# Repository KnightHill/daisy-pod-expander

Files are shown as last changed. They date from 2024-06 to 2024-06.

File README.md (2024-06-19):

# POD Expander

Expander board for the [ElectroSmith POD](https://www.electro-smith.com/daisy/pod)

## OLED Expander (v 1.1)

Final version of the expander, adding OLED display, two potentiometers, and one button.
Firmware, KiCad 7 project and Gerber files included.

## List of parts
- 1 16 pin female header
- 1 7 pin female header
- 2 [10k potentiometers](https://www.amazon.com/uxcell-Carbon-Potentiometer-Variable-Resistors/dp/B07STNVSC3)
- 1 [tactile switch](https://www.amazon.com/QTEATAK-Momentary-Tactile-Button-Switch/dp/B07VSNN9S2/)
- 1 [OLED SPI display (SSD1306)](https://www.amazon.com/HiLetgo-Serial-128X64-Display-Color/dp/B01MQPQF24/)

## PCB
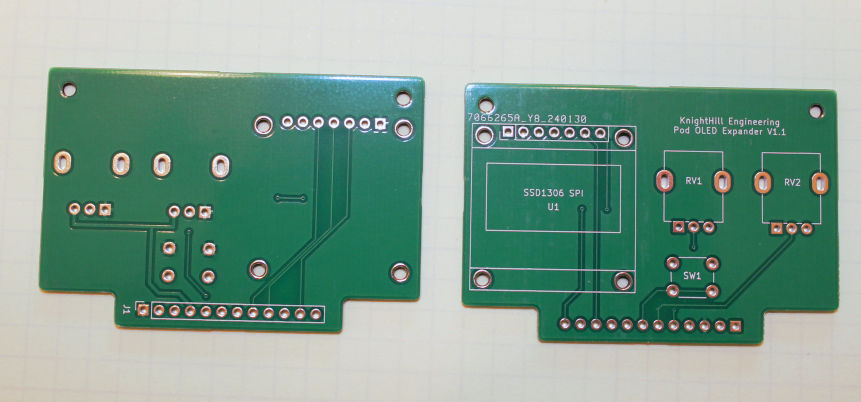
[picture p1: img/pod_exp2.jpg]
PCB

## Populated board
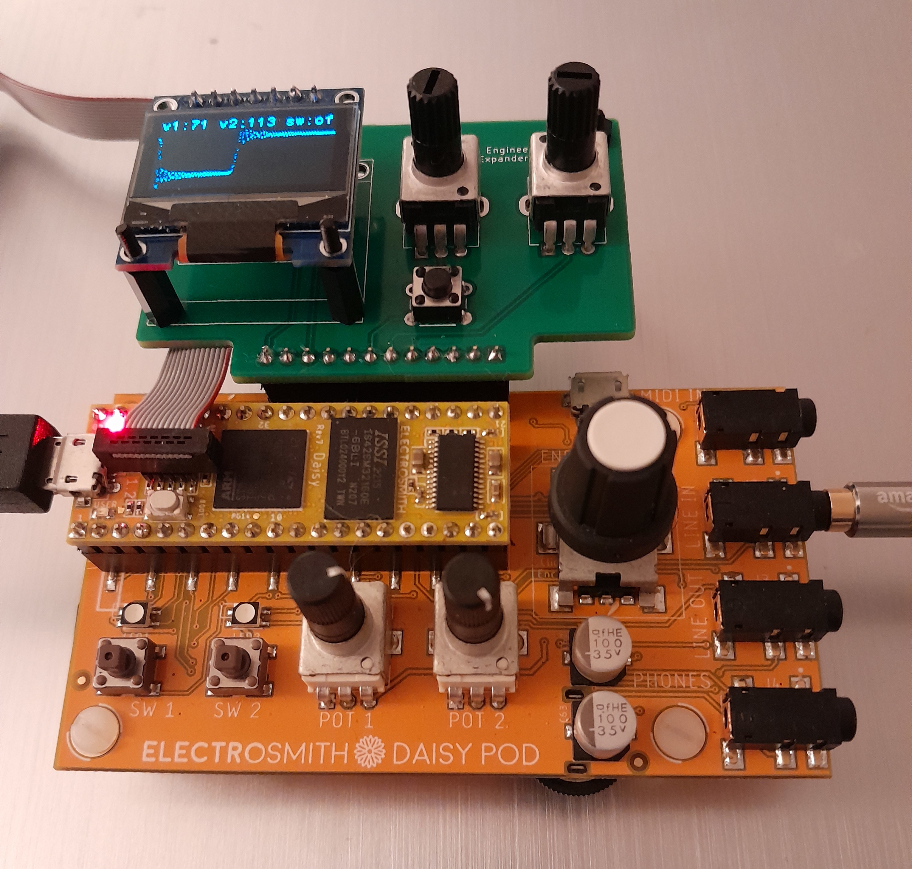
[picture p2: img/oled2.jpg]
OLED Expander v1.1


 # Disclamer

This is a hobby project. I am not affiliated with ElectroSmith in any way. I accept no responsibility for damage to you Daisy Seed, external equipment or anything else. You use this code and hardware at your own risk. All names, logos, images, and brands are property of their respective owners.

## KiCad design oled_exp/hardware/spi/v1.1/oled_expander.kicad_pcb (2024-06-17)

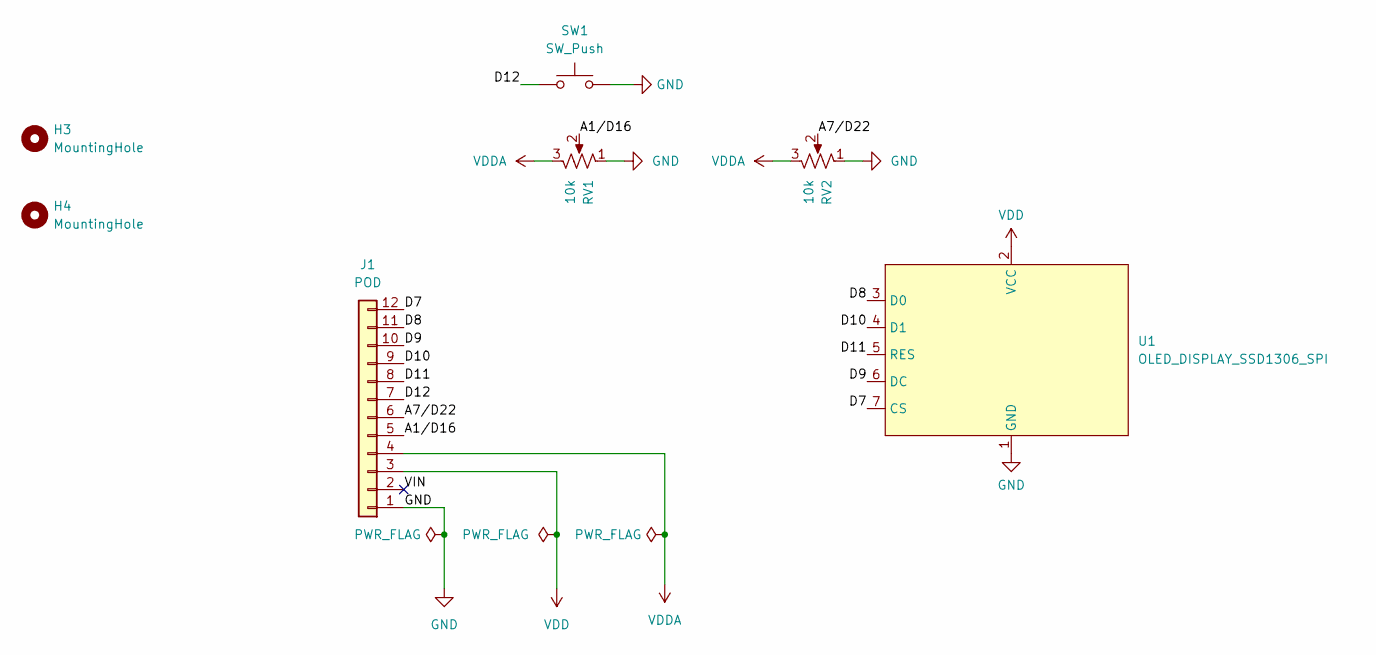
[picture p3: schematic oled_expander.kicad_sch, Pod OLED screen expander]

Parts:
H3, H4: MountingHole; MountingHole_2.2mm_M2
J1: POD; PinSocket_1x12_P2.54mm_Vertical
RV1, RV2: 10k; Potentiometer_uxcel_9mm_Single_Vertical
SW1: SW_Push; SW_PUSH_6mm
U1: OLED_DISPLAY_SSD1306_SPI; HiLetgo_OLED_SPI

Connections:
/A1/D16: J1.5, RV1.2
/A7/D22: J1.6, RV2.2
/D7: J1.12, U1.7 (CS)
/D8: J1.11, U1.3 (D0)
/D9: J1.10, U1.6 (DC)
/D10: J1.9, U1.4 (D1)
/D11: J1.8, U1.5 (RES)
/D12: J1.7, SW1.1
/VIN: J1.2
GND: J1.1, RV1.1, RV2.1, SW1.2, U1.1 (GND)
VDD: J1.3, U1.2 (VCC)
VDDA: J1.4, RV1.3, RV2.3

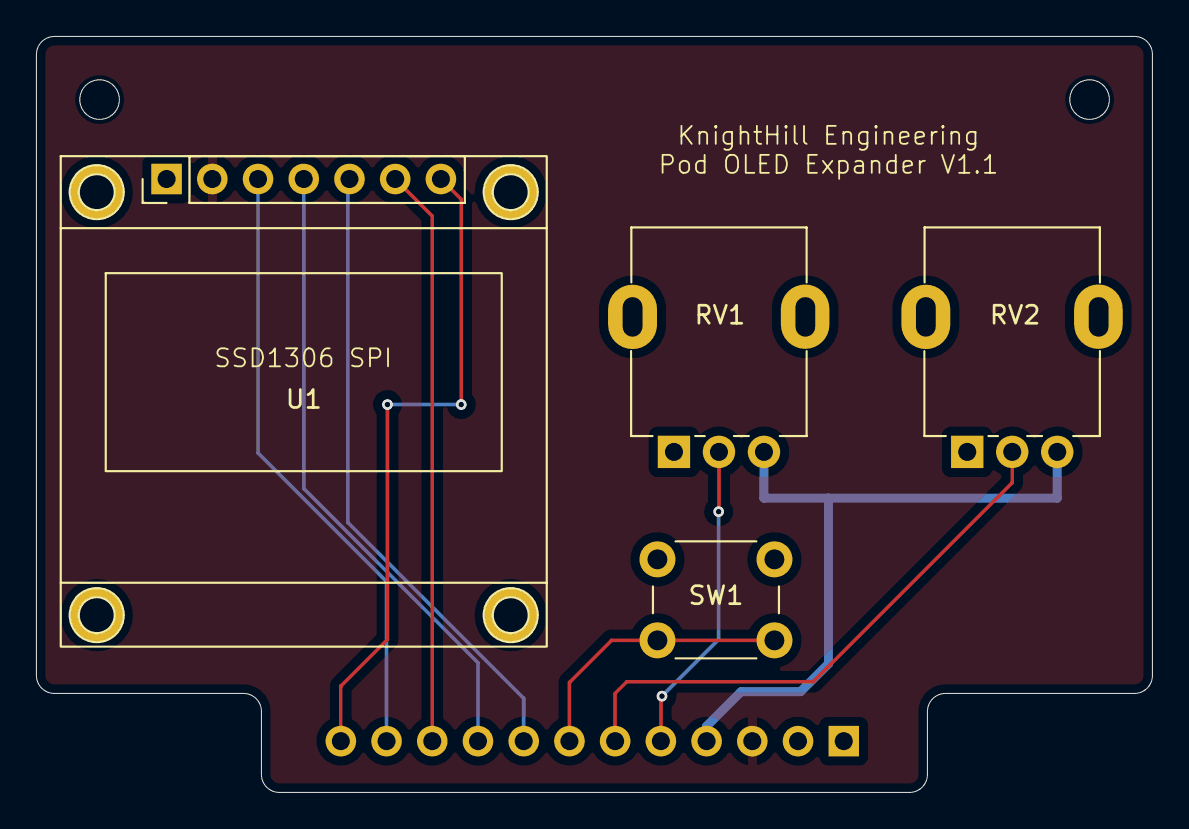
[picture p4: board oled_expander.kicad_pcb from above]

Board: 2 copper layers, 62.0 x 42.0 mm, 7 parts (1 on the bottom side), 11 nets.

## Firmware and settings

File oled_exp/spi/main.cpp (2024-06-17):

#include <stdio.h>
#include <string.h>
#include "daisy_seed.h"
#include "dev/oled_ssd130x.h"
#include "oled_exp.h"

using namespace daisy;

static OledExp hw;

static char line1[128];
static char line2[128];
static float knob1_value;
static float knob2_value;
static bool sw1;

const uint16_t ScreenWidth = 128;
static float m_scopeBuffer[ScreenWidth];
static uint16_t m_bufferIndex;

void show_info()
{
  Rectangle topRowRect(hw.display.Width(), 20);
  Rectangle secondRowRect(0, 21, hw.display.Width(), 10);
  hw.display.Fill(false);
  hw.display.WriteStringAligned(line1, Font_11x18, topRowRect, Alignment::centered, true);
  hw.display.WriteStringAligned(line2, Font_7x10, secondRowRect, Alignment::centered, true);
  hw.display.Update();
  System::Delay(1000);
}

void show_logo()
{
  sprintf(line1, "KnightHill");
  sprintf(line2, "Engineering");
  show_info();
}

void show_product()
{
  sprintf(line1, "OLED SPI Exp");
  sprintf(line2, "version 1.1");
  show_info();
}

void draw_ui(float v1, float v2, bool sw1)
{
  uint16_t center = hw.display.Height() / 2;
  uint8_t pot1 = (uint8_t)(127.0f * v1);
  uint8_t pot2 = (uint8_t)(127.0f * v2);
  sprintf(line1, "v1:%d v2:%d sw:%s", pot1, pot2, sw1 ? "on" : "off");
  hw.display.Fill(false);
  hw.display.SetCursor(0, 0);
  hw.display.WriteString(line1, Font_7x10, true);

  for (uint16_t i = 0; i < ScreenWidth; i++) {
    hw.display.DrawPixel(i, m_scopeBuffer[i] * center * knob1_value * 10 + center, true);
  }
  hw.display.Update();
}

void Callback(AudioHandle::InputBuffer in, AudioHandle::OutputBuffer out, size_t size)
{
  for (size_t i = 0; i < size; i++) {
    m_scopeBuffer[m_bufferIndex] = (IN_L[i] + IN_R[i]) / 2.0f;
    if (++m_bufferIndex >= ScreenWidth)
      m_bufferIndex = 0;
    OUT_L[i] = IN_L[i];
    OUT_R[i] = IN_R[i];
  }
}

int main(void)
{
  knob1_value = 0;
  knob2_value = 0;
  m_bufferIndex = 0;

  for (uint16_t i = 0; i < ScreenWidth; i++) {
    m_scopeBuffer[i] = 0;
  }

  hw.Init();
  hw.SetAudioBlockSize(8);

  hw.StartAdc();

  show_logo();
  show_product();

  hw.StartAudio(Callback);

  while (1) {
    hw.ProcessDigitalControls();

    knob1_value = hw.knob3.Process();
    knob2_value = hw.knob4.Process();

    if (hw.button3.RisingEdge()) {
      sw1 = !sw1;
    }

    draw_ui(knob1_value, knob2_value, sw1);

    // System::Delay(5);
  }
}

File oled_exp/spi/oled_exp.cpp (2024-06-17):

#include "dev/oled_ssd130x.h"
#include "oled_exp.h"

#ifndef SAMPLE_RATE
// #define SAMPLE_RATE DSY_AUDIO_SAMPLE_RATE
#define SAMPLE_RATE 48014.f
#endif

using namespace daisy;

// # Rev3 and Rev4 with newest pinout.
// Compatible with Seed Rev3 and Rev4
constexpr Pin SW_1_PIN = seed::D27;
constexpr Pin SW_2_PIN = seed::D28;
constexpr Pin SW_3_PIN = seed::D12;

constexpr Pin ENC_A_PIN = seed::D26;
constexpr Pin ENC_B_PIN = seed::D25;
constexpr Pin ENC_CLICK_PIN = seed::D13;

constexpr Pin LED_1_R_PIN = seed::D20;
constexpr Pin LED_1_G_PIN = seed::D19;
constexpr Pin LED_1_B_PIN = seed::D18;
constexpr Pin LED_2_R_PIN = seed::D17;
constexpr Pin LED_2_G_PIN = seed::D24;
constexpr Pin LED_2_B_PIN = seed::D23;

constexpr Pin KNOB_1_PIN = seed::D21;
constexpr Pin KNOB_2_PIN = seed::D15;
constexpr Pin KNOB_3_PIN = seed::D16;
constexpr Pin KNOB_4_PIN = seed::D22;

constexpr Pin OLED_DC_PIN = seed::D9;
constexpr Pin OLED_RESET_PIN = seed::D11;

using namespace daisy;

void OledExp::Init(bool boost)
{
  // Set Some numbers up for accessors.
  // Initialize the hardware.
  seed.Configure();
  seed.Init(boost);
  InitButtons();
  InitEncoder();
  InitLeds();
  InitKnobs();
  InitMidi();
  InitDisplay();
  SetAudioBlockSize(48);
}

void OledExp::DelayMs(size_t del) { seed.DelayMs(del); }

void OledExp::SetHidUpdateRates()
{
  for (int i = 0; i < KNOB_LAST; i++) {
    knobs[i]->SetSampleRate(AudioCallbackRate());
  }
}

void OledExp::StartAudio(AudioHandle::InterleavingAudioCallback cb) { seed.StartAudio(cb); }

void OledExp::StartAudio(AudioHandle::AudioCallback cb) { seed.StartAudio(cb); }

void OledExp::ChangeAudioCallback(AudioHandle::InterleavingAudioCallback cb) { seed.ChangeAudioCallback(cb); }

void OledExp::ChangeAudioCallback(AudioHandle::AudioCallback cb) { seed.ChangeAudioCallback(cb); }

void OledExp::StopAudio() { seed.StopAudio(); }

void OledExp::SetAudioBlockSize(size_t size)
{
  seed.SetAudioBlockSize(size);
  SetHidUpdateRates();
}

size_t OledExp::AudioBlockSize() { return seed.AudioBlockSize(); }

void OledExp::SetAudioSampleRate(SaiHandle::Config::SampleRate samplerate)
{
  seed.SetAudioSampleRate(samplerate);
  SetHidUpdateRates();
}

float OledExp::AudioSampleRate() { return seed.AudioSampleRate(); }

float OledExp::AudioCallbackRate() { return seed.AudioCallbackRate(); }

void OledExp::StartAdc() { seed.adc.Start(); }

void OledExp::StopAdc() { seed.adc.Stop(); }

void OledExp::ProcessAnalogControls()
{
  knob1.Process();
  knob2.Process();
  knob3.Process();
  knob4.Process();
}

float OledExp::GetKnobValue(Knob k)
{
  size_t idx;
  idx = k < KNOB_LAST ? k : KNOB_1;
  return knobs[idx]->Value();
}

void OledExp::ProcessDigitalControls()
{
  encoder.Debounce();
  button1.Debounce();
  button2.Debounce();
  button3.Debounce();
}

void OledExp::ClearLeds()
{
  // Using Color
  Color c;
  c.Init(Color::PresetColor::OFF);
  led1.SetColor(c);
  led2.SetColor(c);
  // Without
  // led1.Set(0.0f, 0.0f, 0.0f);
  // led2.Set(0.0f, 0.0f, 0.0f);
}

void OledExp::UpdateLeds()
{
  led1.Update();
  led2.Update();
}

void OledExp::InitButtons()
{
  button1.Init(SW_1_PIN);
  button2.Init(SW_2_PIN);
  button3.Init(SW_3_PIN);

  buttons[BUTTON_1] = &button1;
  buttons[BUTTON_2] = &button2;
  buttons[BUTTON_3] = &button3;
}

void OledExp::InitEncoder() { encoder.Init(ENC_A_PIN, ENC_B_PIN, ENC_CLICK_PIN); }

void OledExp::InitLeds()
{
  led1.Init(LED_1_R_PIN, LED_1_G_PIN, LED_1_B_PIN, true);
  led2.Init(LED_2_R_PIN, LED_2_G_PIN, LED_2_B_PIN, true);

  ClearLeds();
  UpdateLeds();
}

void OledExp::InitKnobs()
{
  // Configure the ADC channels using the desired pin
  AdcChannelConfig knob_init[KNOB_LAST];
  knob_init[KNOB_1].InitSingle(KNOB_1_PIN);
  knob_init[KNOB_2].InitSingle(KNOB_2_PIN);
  knob_init[KNOB_3].InitSingle(KNOB_3_PIN);
  knob_init[KNOB_4].InitSingle(KNOB_4_PIN);
  // Initialize with the knob init struct w/ 2 members
  // Set Oversampling to 32x
  seed.adc.Init(knob_init, KNOB_LAST);
  // Make an array of pointers to the knobs.
  knobs[KNOB_1] = &knob1;
  knobs[KNOB_2] = &knob2;
  knobs[KNOB_3] = &knob3;
  knobs[KNOB_4] = &knob4;
  for (int i = 0; i < KNOB_LAST; i++) {
    knobs[i]->Init(seed.adc.GetPtr(i), seed.AudioCallbackRate());
  }
}

void OledExp::InitMidi()
{
  MidiUartHandler::Config midi_config;
  midi.Init(midi_config);
}

void OledExp::InitDisplay()
{
  MyOledDisplay::Config disp_cfg;
  disp_cfg.driver_config.transport_config.pin_config.dc = OLED_DC_PIN;
  disp_cfg.driver_config.transport_config.pin_config.reset = OLED_RESET_PIN;
  display.Init(disp_cfg);
}
